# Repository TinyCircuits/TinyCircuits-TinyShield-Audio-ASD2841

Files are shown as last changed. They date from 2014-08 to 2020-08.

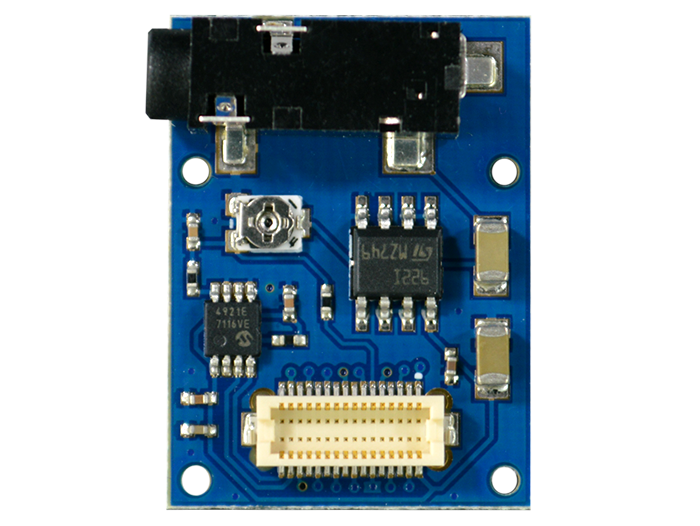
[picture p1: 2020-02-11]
images/ASD2841-R-Tutorial-Image-01.png

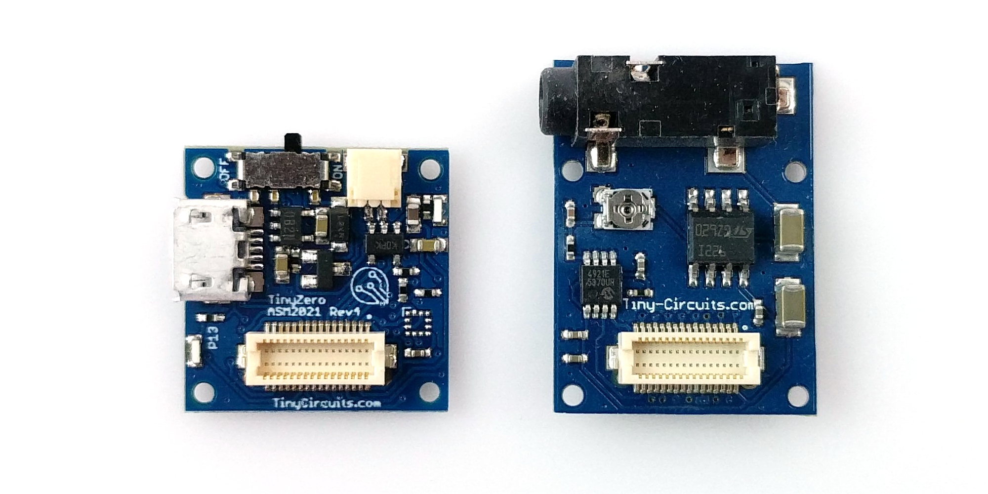
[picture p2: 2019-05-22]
images/ASD2841-R-Tutorial-Image-02.jpg

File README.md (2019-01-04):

# TinyCircuits TinyShield Audio Board
# ASD2841 Rev5

The design files are locate under design_files/ for the TinyCircuits ASD2841 Rev 4 PCB.  This is a TinyShield board (20mm x 27.14mm) that has audio circuit and a headset connector.

Format is in Cadsoft Eagle format - Eagle version 6.2 was used for the original design.

For more infomation on this, check out the product page at TinyCircuits.com:  https://tinycircuits.com/collections/audio/products/audio-tinyshield

# License:

Design by TinyCircuits.
All design files are released under the Creative Commons Attribution Share-Alike 3.0 License, see the following link for details: http://creativecommons.org/licenses/by-sa/3.0

All text above must be included in any redistribution or derived design

This project uses designs and concepts developed as part of the Arduino project and the LilyPad project.  The TinyCircuits design files themselves (schematics, PCB and libraries) are not directly derived from these works' design files and have been created new, however the concepts and basic architecture behind the TinyDuino and TinyLily products are derived and we thank the hard work of the organizations below for their contributions to open-source hardware:
  
Original Arduino Uno Design by Team Arduino

LilyPad Arduino Design by Leah Buechley and Sparkfun Electronics

Please support the open-source hardware community

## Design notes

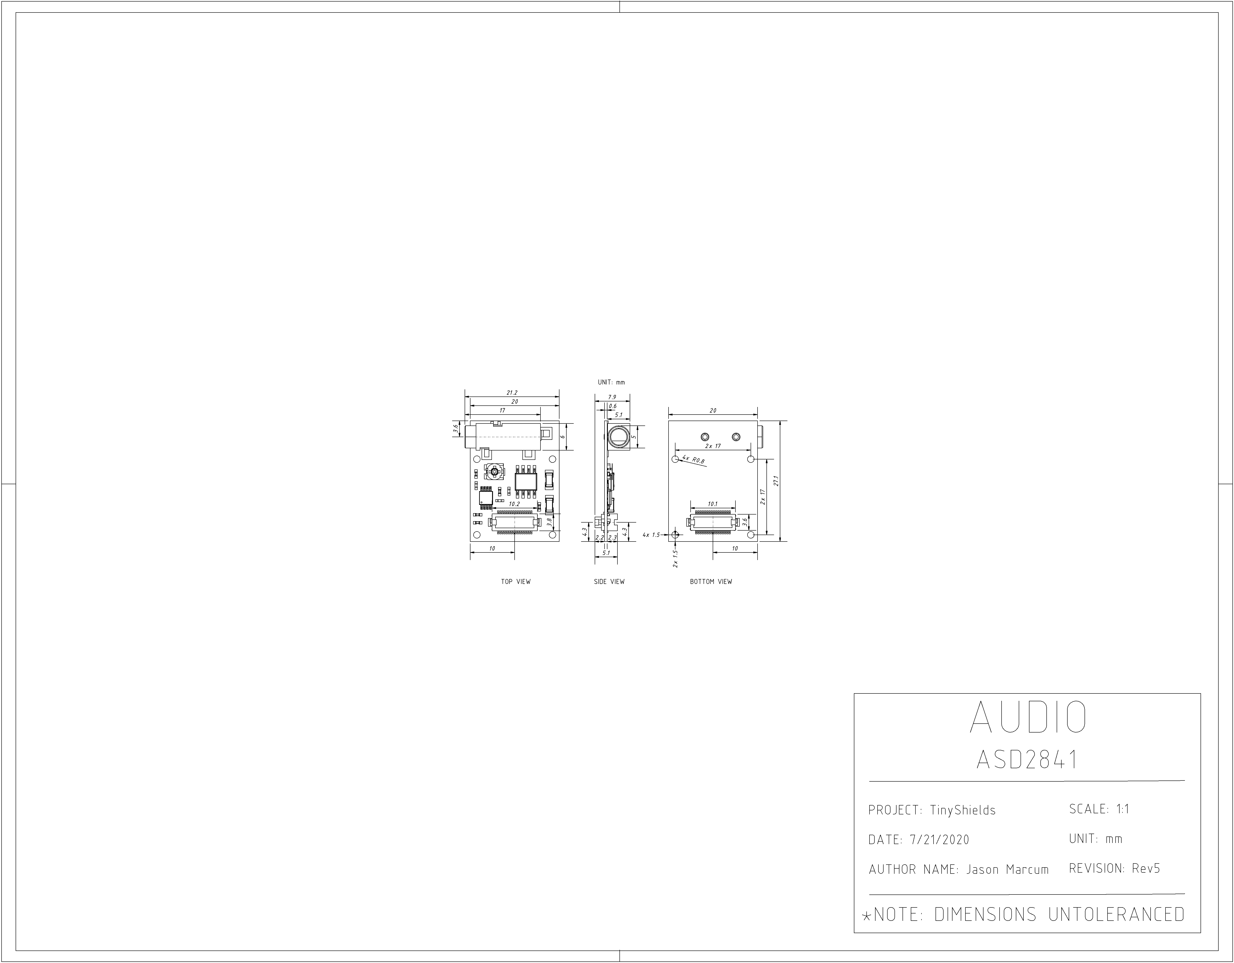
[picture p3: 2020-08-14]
cad/TinyShield_AUDIO_ASD2841_REV5-DETAILED_DRAWING-PNG.png

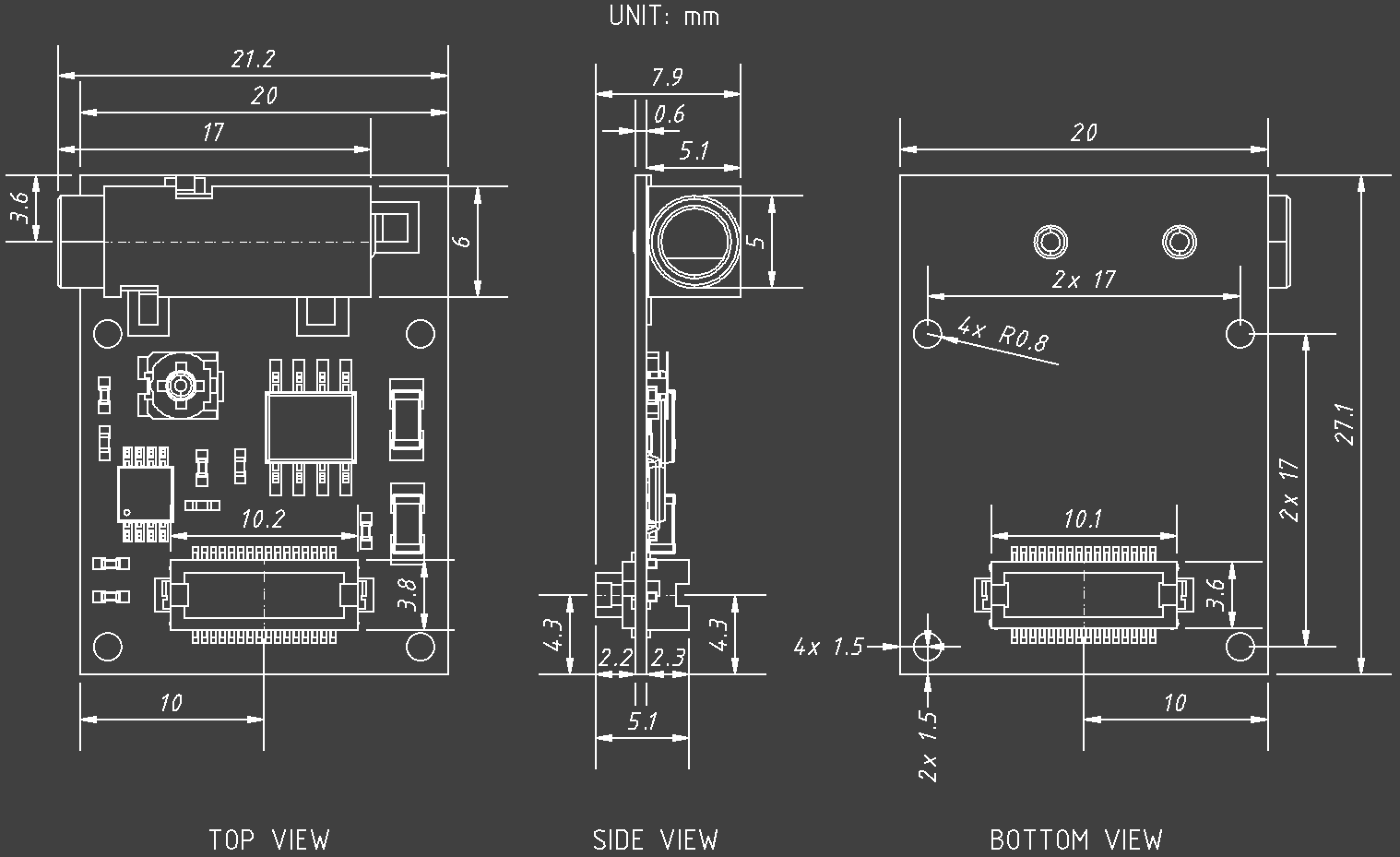
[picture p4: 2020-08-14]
cad/TinyShield_AUDIO_ASD2841_REV5-DETAILED_DRAWING_COMPACT-PNG.png

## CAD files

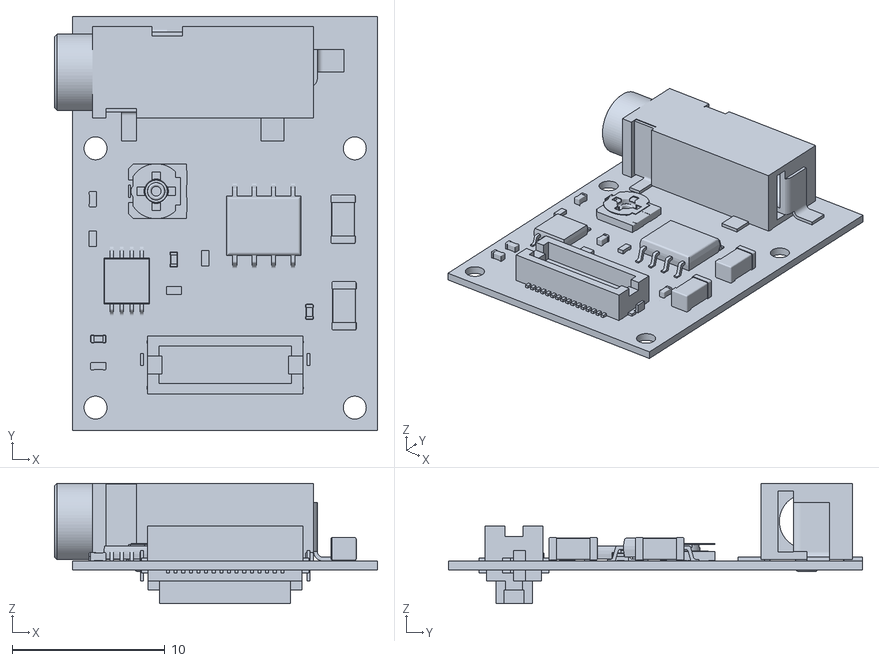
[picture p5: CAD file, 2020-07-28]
cad/TinyShield_AUDIO_ASD2841_REV5-STL.stl
21.2 x 27.1 x 7.90

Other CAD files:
cad/TinyShield_AUDIO_ASD2841_REV5-DETAILED_DRAWING-DXF.dxf

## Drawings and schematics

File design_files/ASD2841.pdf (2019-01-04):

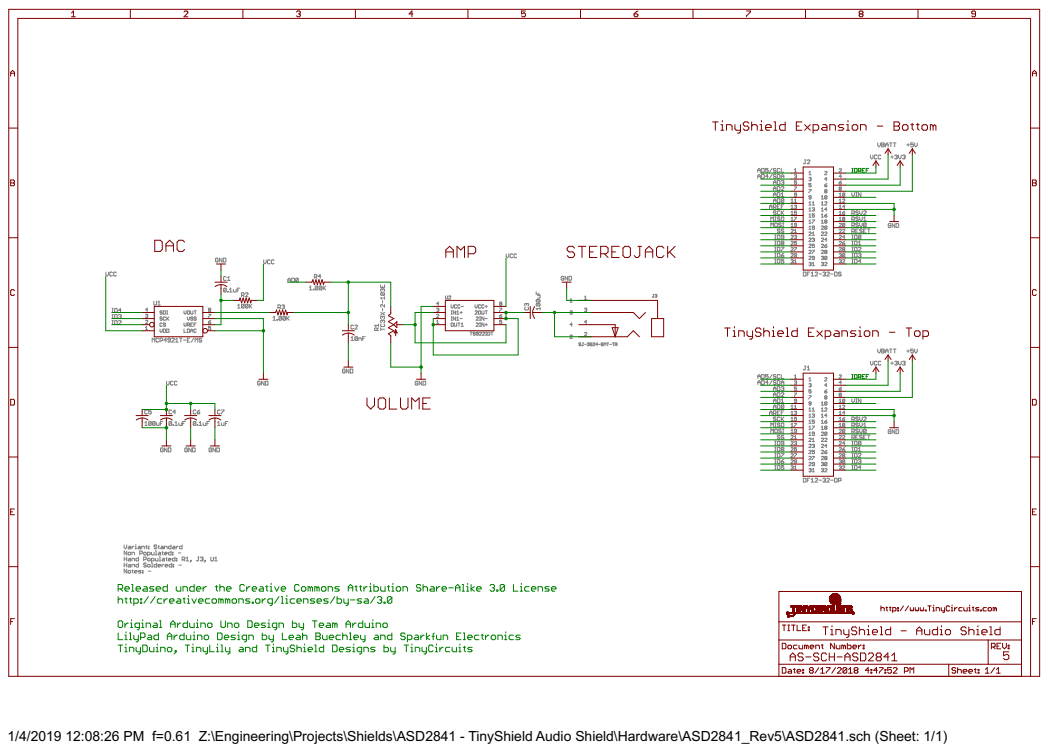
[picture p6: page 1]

1/4/2019 12:08:26 PM f=0.61 Z:\Engineering\Projects\Shields\ASD2841 - TinyShield Audio Shield\Hardware\ASD2841_Rev5\ASD2841.sch (Sheet: 1/1)

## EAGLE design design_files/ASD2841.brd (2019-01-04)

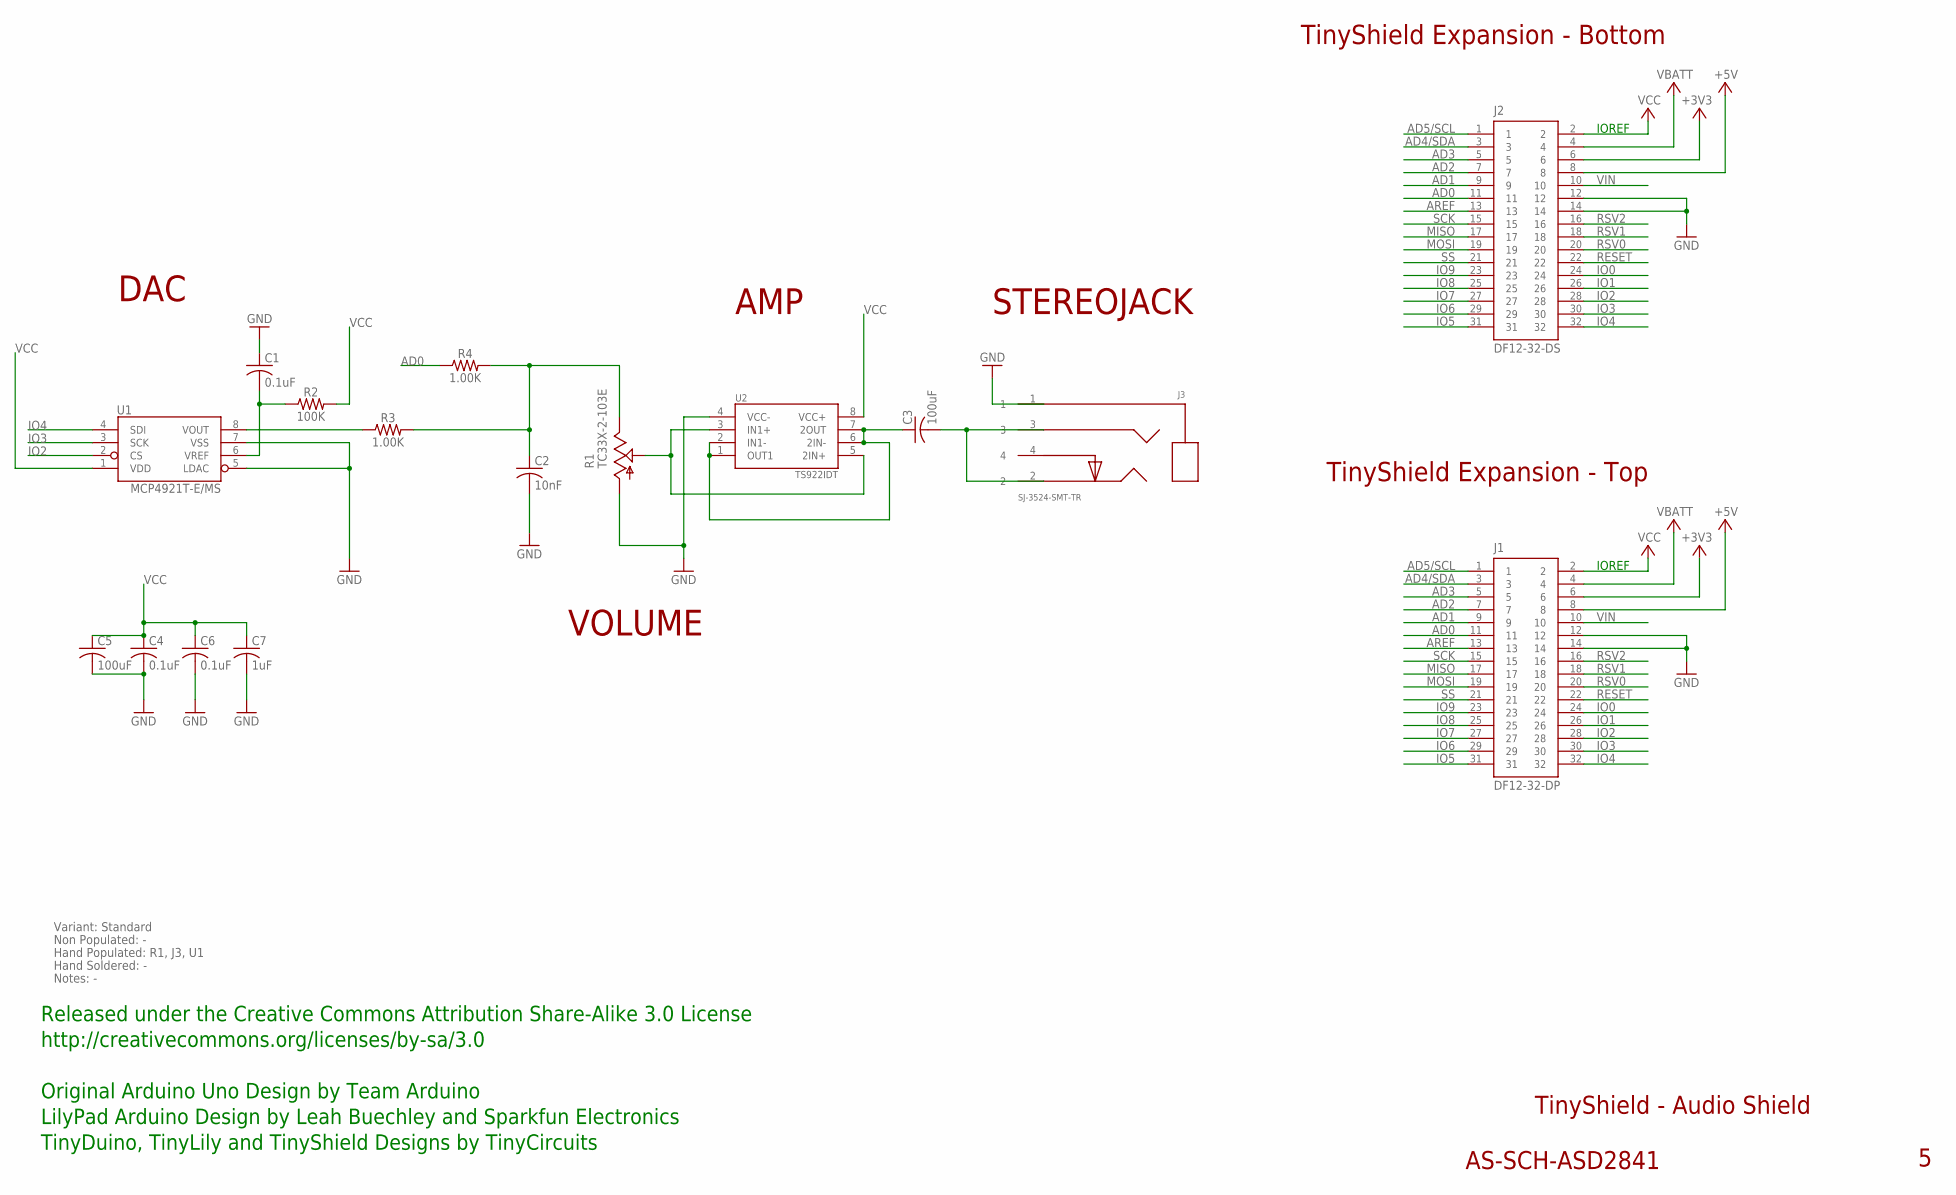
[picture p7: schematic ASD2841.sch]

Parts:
C1, C4: 0.1uF; C0402
C2: 10nF; C0402
C3, C5: 100uF; C1206
C6: 0.1uF; C0402; PARTNO AS-ITM-00008
C7: 1uF; C0402; PARTNO AS-ITM-00105
J1: DF12-32-DP; PARTNO AS-ITM-00015
J2: DF12-32-DS; PARTNO AS-ITM-00012
J3: SJ-3524-SMT-TR
R1: TC33X-2-103E; TC33X-2-104E
R2: 100K; 0402
R3, R4: 1.00K; 0402
U1: MCP4921T-E/MS; MSOP8
U2: TS922IDT; SO-08

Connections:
+3V3: J1.6, J2.6
+5V: J1.8, J2.8
AD0: J1.11, J2.11, R4.1
AD1: J1.9, J2.9
AD2: J1.7, J2.7
AD3: J1.5, J2.5
AD4/SDA: J1.3, J2.3
AD5/SCL: J1.1, J2.1
AREF: J1.13, J2.13
GND: C1.1, C2.2, C4.2, C5.2, C6.2, C7.2, J1.12, J1.14, J2.12, J2.14, J3.1, R1.1 (A), U1.5 (LDAC), U1.7 (VSS), U2.4 (VCC-)
IO0: J1.24, J2.24
IO1: J1.26, J2.26
IO2: J1.28, J2.28, U1.2 (CS)
IO3: J1.30, J2.30, U1.3 (SCK)
IO4: J1.32, J2.32, U1.4 (SDI)
IO5: J1.31, J2.31
IO6: J1.29, J2.29
IO7: J1.27, J2.27
IO8: J1.25, J2.25
IO9: J1.23, J2.23
MISO: J1.17, J2.17
MOSI: J1.19, J2.19
unnamed: R1.2 (S), U2.3 (IN1+), U2.5 (2IN+)
unnamed: C3.1, U2.1 (OUT1), U2.2 (IN1-), U2.6 (2IN-), U2.7 (2OUT)
unnamed: C1.2, R2.1, U1.6 (VREF)
unnamed: R3.1, U1.8 (VOUT)
unnamed: C2.1, R1.3 (E), R3.2, R4.2
unnamed: C3.2, J3.2, J3.3
RESET: J1.22, J2.22
RSV0: J1.20, J2.20
RSV1: J1.18, J2.18
RSV2: J1.16, J2.16
SCK: J1.15, J2.15
SS: J1.21, J2.21
VBATT: J1.4, J2.4
VCC: C4.1, C5.1, C6.1, C7.1, J1.2, J2.2, R2.2, U1.1 (VDD), U2.8 (VCC+)
VIN: J1.10, J2.10

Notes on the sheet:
TinyShield Expansion - Bottom
TinyShield - Audio Shield
AS-SCH-ASD2841
TinyShield Expansion - Top
IOREF
Released under the Creative Commons Attribution Share-Alike 3.0 License
http://creativecommons.org/licenses/by-sa/3.0
LilyPad Arduino Design by Leah Buechley and Sparkfun Electronics
TinyDuino, TinyLily and TinyShield Designs by TinyCircuits
Original Arduino Uno Design by Team Arduino
DAC
AMP
STEREOJACK
VOLUME
Non Populated: -
Hand Populated: R1, J3, U1
Hand Soldered: -
Variant: Standard
Notes: -

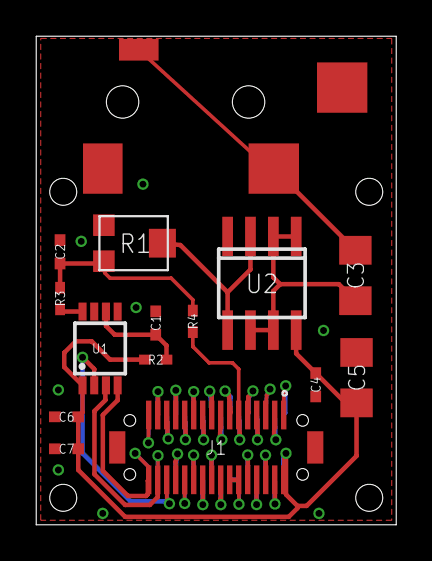
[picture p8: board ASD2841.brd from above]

Board: 2 copper layers, 20.0 x 27.1 mm, 17 parts (1 on the bottom side), 37 nets.

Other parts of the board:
U$1: DOCFIELD-TINYCIRCUITS-PCB

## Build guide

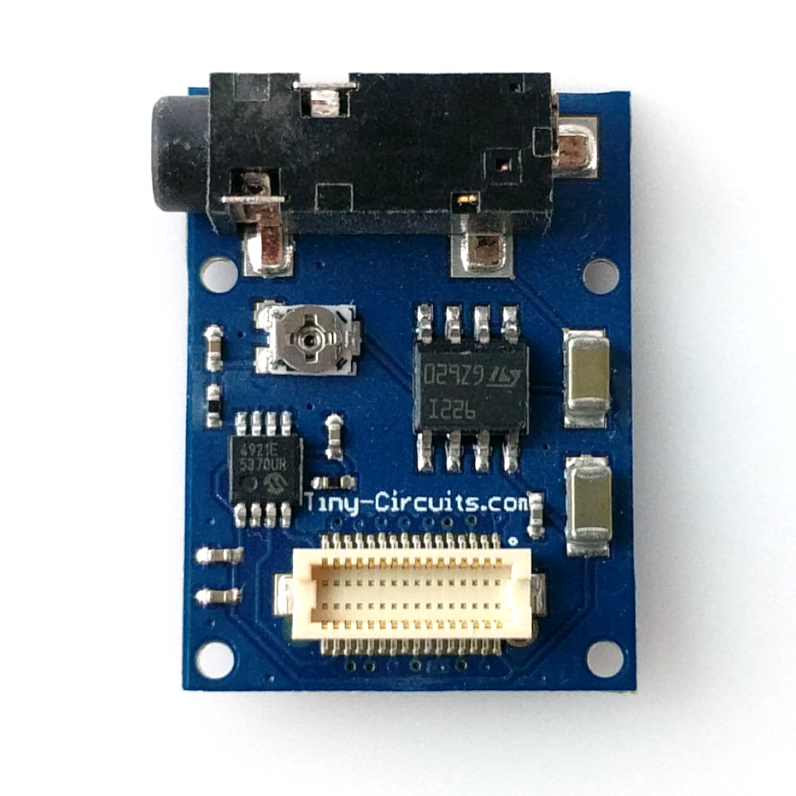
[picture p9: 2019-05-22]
images/ASD2841-R-Tutorial-Image-01.jpg

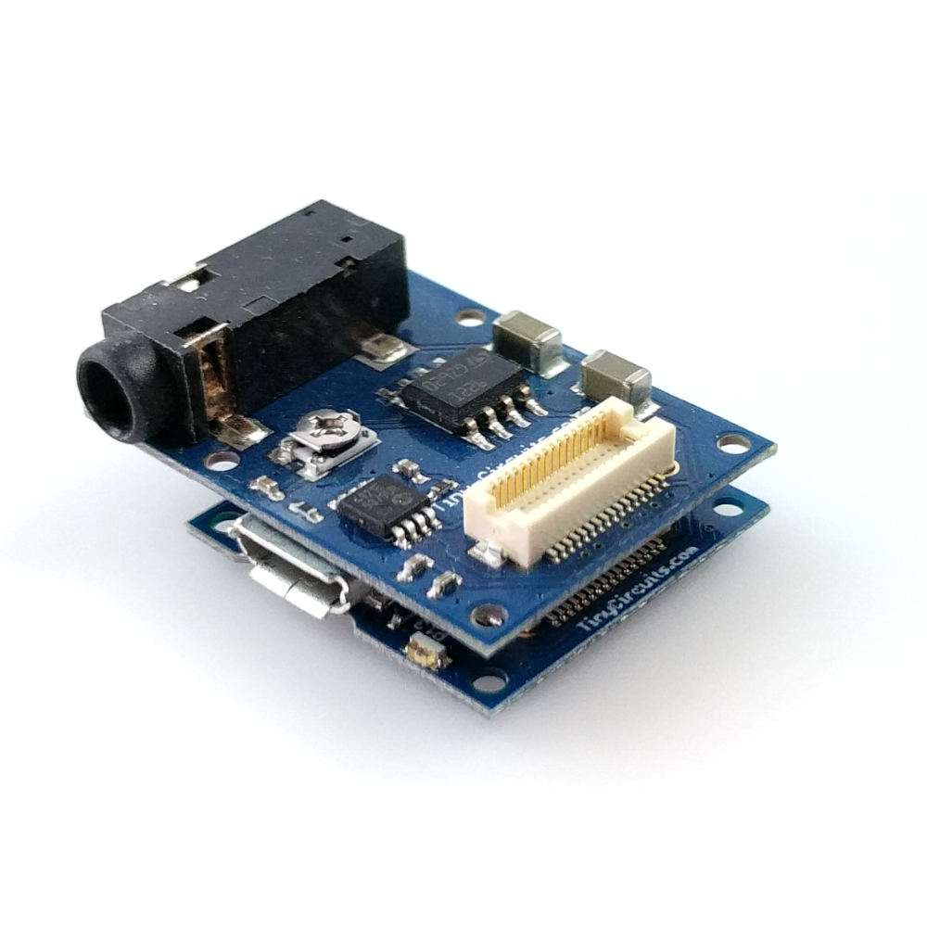
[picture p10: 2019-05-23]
images/ASD2841-R-Tutorial-Image-03.jpg

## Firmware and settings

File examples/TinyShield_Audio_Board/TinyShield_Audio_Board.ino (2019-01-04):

#include "WaveUtil.h"
#include "WaveHC.h"

//in root directory of SD card
char fileName[]="song1.wav";

SdReader card;    // This object holds the information for the card
FatVolume vol;    // This holds the information for the partition on the card
FatReader root;   // This holds the information for the filesystem on the card
FatReader f;      // This holds the information for the file we're play

WaveHC wave;      // This is the only wave (audio) object, since we will only play one at a time



// this handy function will return the number of bytes currently free in RAM, great for debugging!   
int freeRam(void)
{
  extern int  __bss_end; 
  extern int  *__brkval; 
  int free_memory; 
  if((int)__brkval == 0) {
    free_memory = ((int)&free_memory) - ((int)&__bss_end); 
  }
  else {
    free_memory = ((int)&free_memory) - ((int)__brkval); 
  }
  return free_memory; 
} 

void sdErrorCheck(void)
{
  if (!card.errorCode()) return;
  putstring("\n\rSD I/O error: ");
  Serial.print(card.errorCode(), HEX);
  putstring(", ");
  Serial.println(card.errorData(), HEX);
  while(1);
}

void setup() {
  byte i;
  Serial.begin(9600);
  putstring("Free RAM: ");       // This can help with debugging, running out of RAM is bad
  Serial.println(freeRam());      // if this is under 150 bytes it may spell trouble!
  
  // Set the output pins for the DAC control. This pins are defined in the library
  pinMode(2, OUTPUT);
  pinMode(3, OUTPUT);
  pinMode(4, OUTPUT);
 
  // pin13 LED
  pinMode(13, OUTPUT);
 
  if (!card.init()) {         //play with 8 MHz spi (default faster!)  
    putstring_nl("Card init. failed!");  // Something went wrong, lets print out why
    sdErrorCheck();
    while(1);                            // then 'halt' - do nothing!
  }
  
  // enable optimize read - some cards may timeout. Disable if you're having problems
  card.partialBlockRead(true);
 
// Now we will look for a FAT partition!
  uint8_t part;
  for (part = 0; part < 5; part++) {     // we have up to 5 slots to look in
    if (vol.init(card, part)) 
      break;                             // we found one, lets bail
  }
  if (part == 5) {                       // if we ended up not finding one  :(
    putstring_nl("No valid FAT partition!");
    sdErrorCheck();      // Something went wrong, lets print out why
    while(1);                            // then 'halt' - do nothing!
  }
  
  // Lets tell the user about what we found
  putstring("Using partition ");
  Serial.print(part, DEC);
  putstring(", type is FAT");
  Serial.println(vol.fatType(),DEC);     // FAT16 or FAT32?
  
  // Try to open the root directory
  if (!root.openRoot(vol)) {
    putstring_nl("Can't open root dir!"); // Something went wrong,
    while(1);                             // then 'halt' - do nothing!
  }
  
  // Whew! We got past the tough parts.
  putstring_nl("Ready!");


}


void loop() {
  Serial.print("Playing ");
  Serial.println(fileName);
  playfile(fileName);
  int counter=0;
  while(wave.isplaying){
    //Do other stuff while playing
    delay(1000);
    Serial.println(counter++);
  };
}


void playfile(char *name) {
  // see if the wave object is currently doing something
  if (wave.isplaying) {// already playing something, so stop it!
    wave.stop(); // stop it
  }
  // look in the root directory and open the file
  if (!f.open(root, name)) {
    putstring("Couldn't open file "); Serial.print(name); return;
  }
  // OK read the file and turn it into a wave object
  if (!wave.create(f)) {
    putstring_nl("Not a valid WAV"); return;
  }
  
  // ok time to play! start playback
  wave.play();
}

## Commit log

2019-01-04 update format
    [ASD2841.brd, ASD2841.sch]
2020-07-28 Add CAD data
    [TinyShield_AUDIO_ASD2841_REV5-DETAILED_DRAWING-DXF.dxf, TinyShield_AUDIO_ASD2841_REV5-STL.stl]
2020-08-14 Update CAD drawing
    [TinyShield_AUDIO_ASD2841_REV5-DETAILED_DRAWING-DXF.dxf]
